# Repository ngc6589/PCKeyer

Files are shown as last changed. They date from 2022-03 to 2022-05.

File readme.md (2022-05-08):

# PCKeyer
## 概要

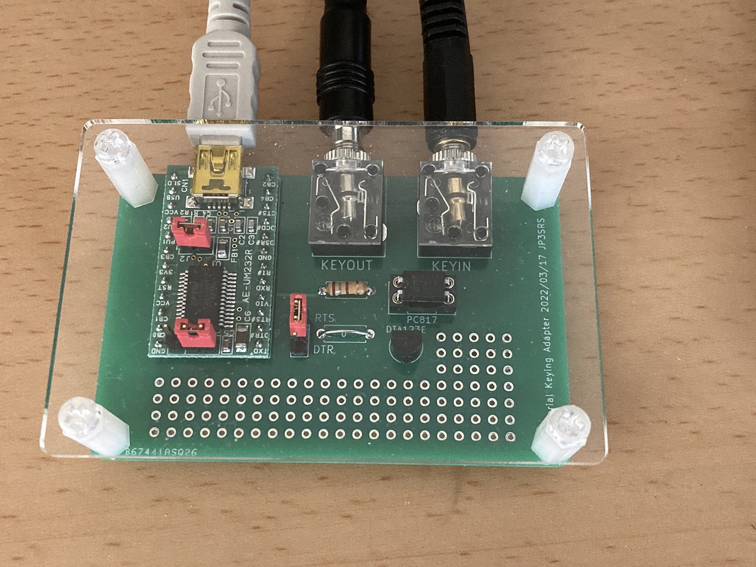
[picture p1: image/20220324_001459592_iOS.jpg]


PCKeyer はお手持ちのエレキーと無線機の KEY ジャック間に入れることで、PCキーイング機能を追加するためのアダプタ基板です。

CTESTWIN や DSCW (Didital Sound CW) などから、シリアルポートの RTS/DTR を使用したキーイングをすることが出来ます。

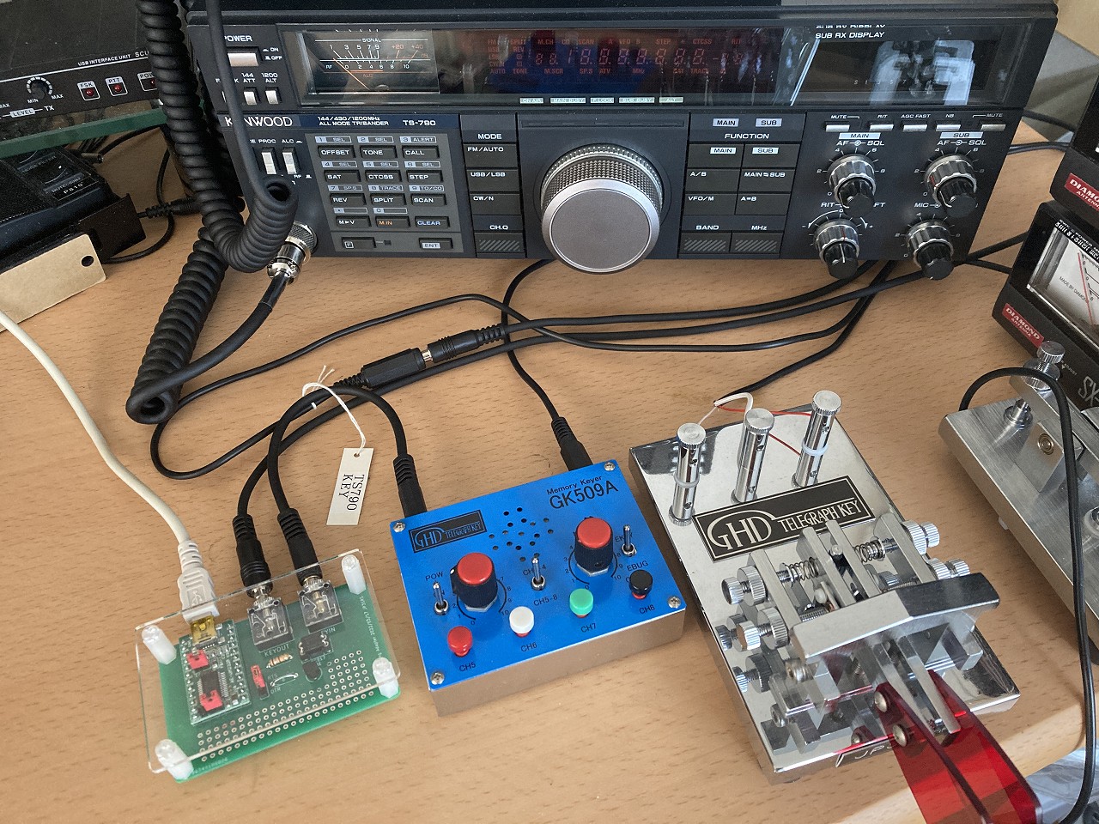
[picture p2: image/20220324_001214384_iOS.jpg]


パドル -> エレキー -> 当アダプタ -> リグのキージャック という接続です。

## プリント基板について

基板は https://www.em9system.com/?p=956 にて頒布いたします。

## 部品表  

|部品名|秋月型番|数量|その他|
|-----|-----|----|----|
|FT232RL USBシリアル変換モジュールキット|K-06693|1||
|抵抗入トランジスタ DTA123EL|I-12465|1||
|フォトカプラ PC817|I-13765|1||
|丸ピンICソケット(4P)|P-14240|1||
|カーボン抵抗(炭素皮膜抵抗) 1/4W180Ω(100本入)|R-25181|1袋||
|3.5mmステレオミニジャック MJ-352W-O|C-08958|2||
|ジャンパーピン赤(2.54mmピッチ)(25個入)|P-03688|1袋||
|ピンヘッダ 1×40 (40P)|C-00167|1||
|＜以下オプション＞
|C基板用アクリルパネル(アクリル板) 2mm厚(透明)|P-09853|1|スモークは P-09854|
|3mmプラネジ(7mm)+六角スペーサー(14mm)セット|P-01861|1||
|接着シール付き透明ゴムクッション (4個入)|P-10080|1||

抵抗入トランジスタ DTA123EL は、他のデジトラに置き換え可能です。または2SA1015 などの汎用 PNP トランジスタと 2.2k 程度のベース抵抗の組み合わせでも OK です。足の並びは ECB です。  
フォトカプラは TLP521 など汎用品置き換え可能です。  

## 組み立て

- FT232RL USBシリアル変換モジュールキットは、 USB からの 5V で動作させたいのでジャンパーJ1 2-3間ショート、J2 ショートとします。
- 0「ゼロ」と書かれた抵抗部分は、抵抗入りトランジスタを使用する場合はショートです。2SA1015 など汎用 PNP トランジスタを使うときだけここにベース抵抗を取り付けます。

## 注意事項

- 無線機の KEY 入力はストレートキーの設定にして下さい
- フォトカプラの耐圧から、真空管式リグのキーイングは出来ません。
- 本機を USB に差した時、 USB シリアルアダプタの初期化途中6回程送信状態になります。無線機が ON の状態だとその間送信状態となります。注意ください。

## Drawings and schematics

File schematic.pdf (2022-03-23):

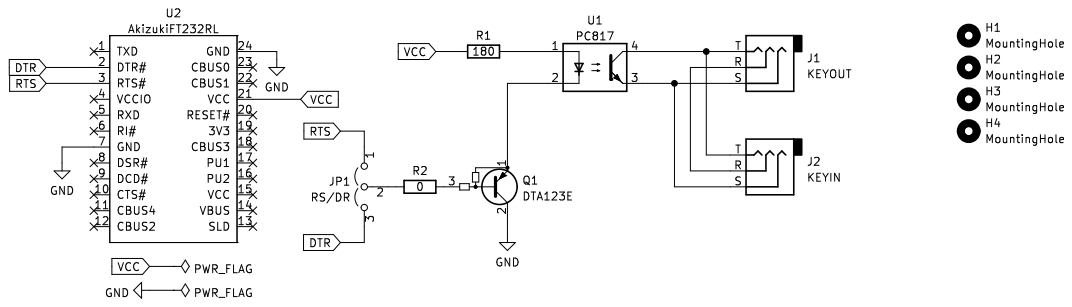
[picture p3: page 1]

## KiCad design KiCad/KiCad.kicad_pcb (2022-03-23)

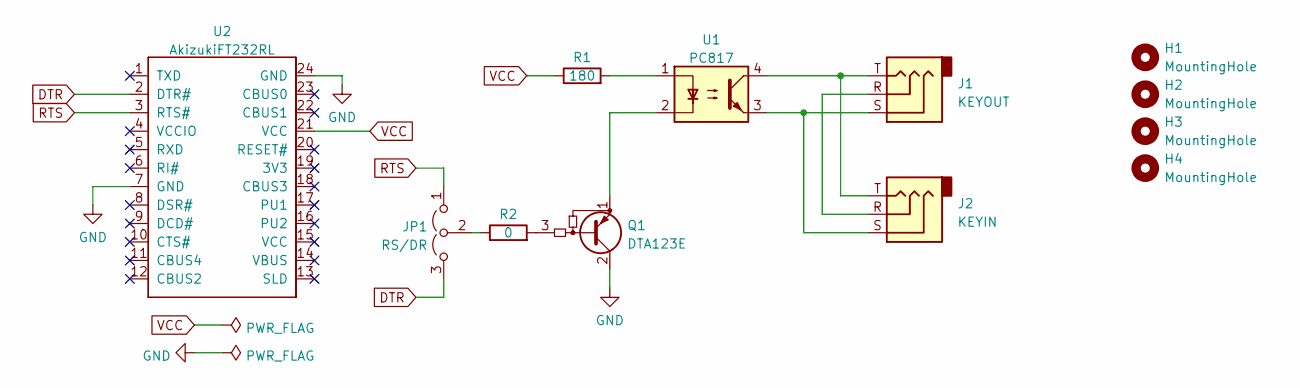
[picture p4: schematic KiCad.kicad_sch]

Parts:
H1, H2, H3, H4: MountingHole; MountingHole_3.2mm_M3
J1: KEYOUT; MJ-352W-0
J2: KEYIN; MJ-352W-0
JP1: RS/DR; PinHeader_1x03_P2.54mm_Vertical
Q1: DTA123E; TO-92_HandSolder
R1: 180; R_Axial_DIN0207_L6.3mm_D2.5mm_P7.62mm_Horizontal
R2: 0; R_Axial_DIN0207_L6.3mm_D2.5mm_P7.62mm_Horizontal
U1: PC817; DIP-4_W7.62mm_Socket_LongPads
U2: AkizukiFT232RL; DIP-24_W15.24mm_Socket_LongPads

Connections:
DTR: JP1.3 (B), U2.2 (DTR#)
GND: Q1.2 (C), U2.7 (GND), U2.24 (GND)
unnamed: J1.R, J2.R
unnamed: J1.S, J2.S, U1.3
unnamed: J1.T, J2.T, U1.4
unnamed: JP1.2 (C), R2.1
unnamed: Q1.1 (E), U1.2
unnamed: Q1.3 (B), R2.2
unnamed: R1.2, U1.1
RTS: JP1.1 (A), U2.3 (RTS#)
VCC: R1.1, U2.21 (VCC)

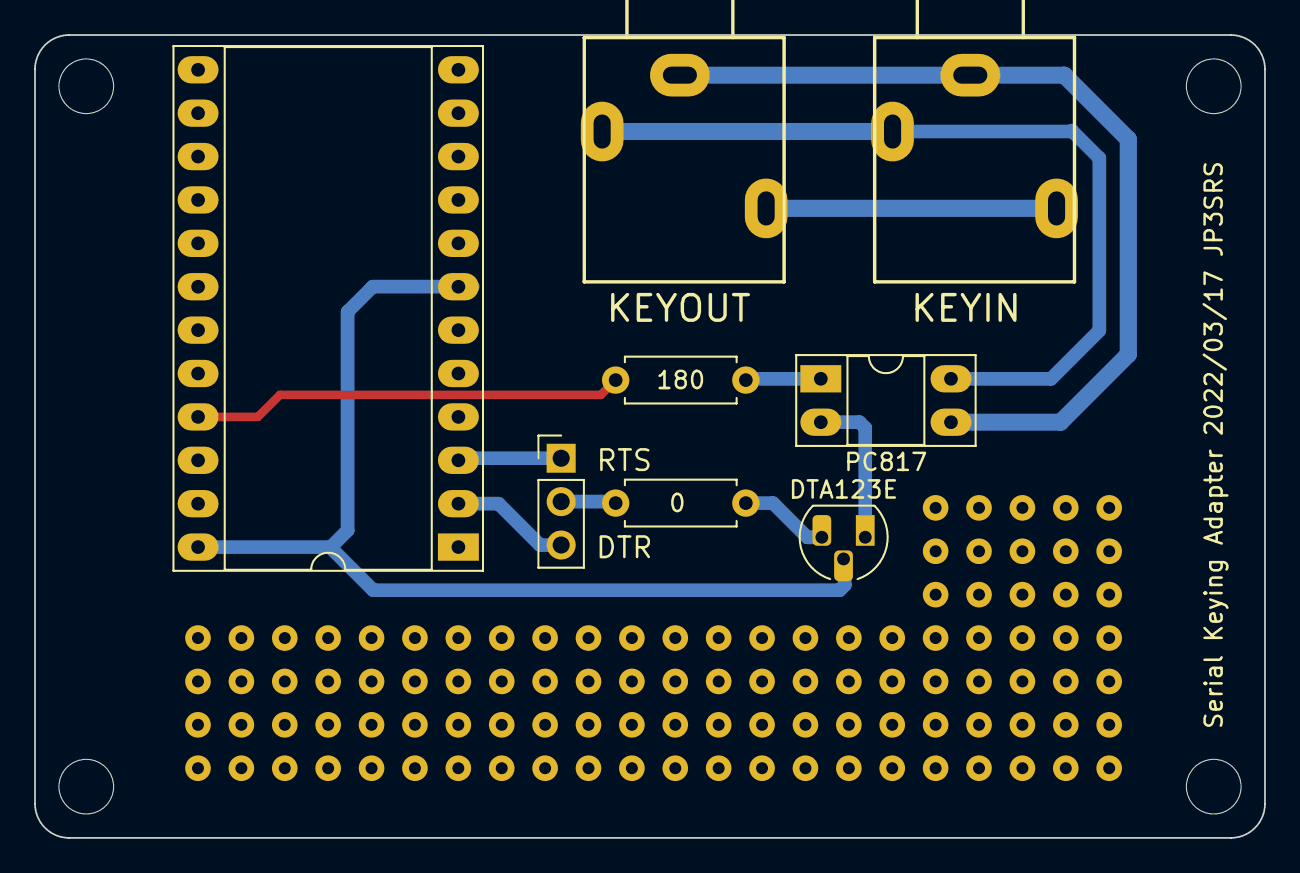
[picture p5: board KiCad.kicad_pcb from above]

Board: 2 copper layers, 72.0 x 47.0 mm, 12 parts (0 on the bottom side), 11 nets.
